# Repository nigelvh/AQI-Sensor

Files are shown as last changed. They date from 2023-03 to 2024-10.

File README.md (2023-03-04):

# AQI Sensor
Custom hardware for measuring the Air Quality Index along with environmental Temperature, Pressure, and Humidity. [Read more about the project here!](https://digitalnigel.com/wordpress/?p=3436)

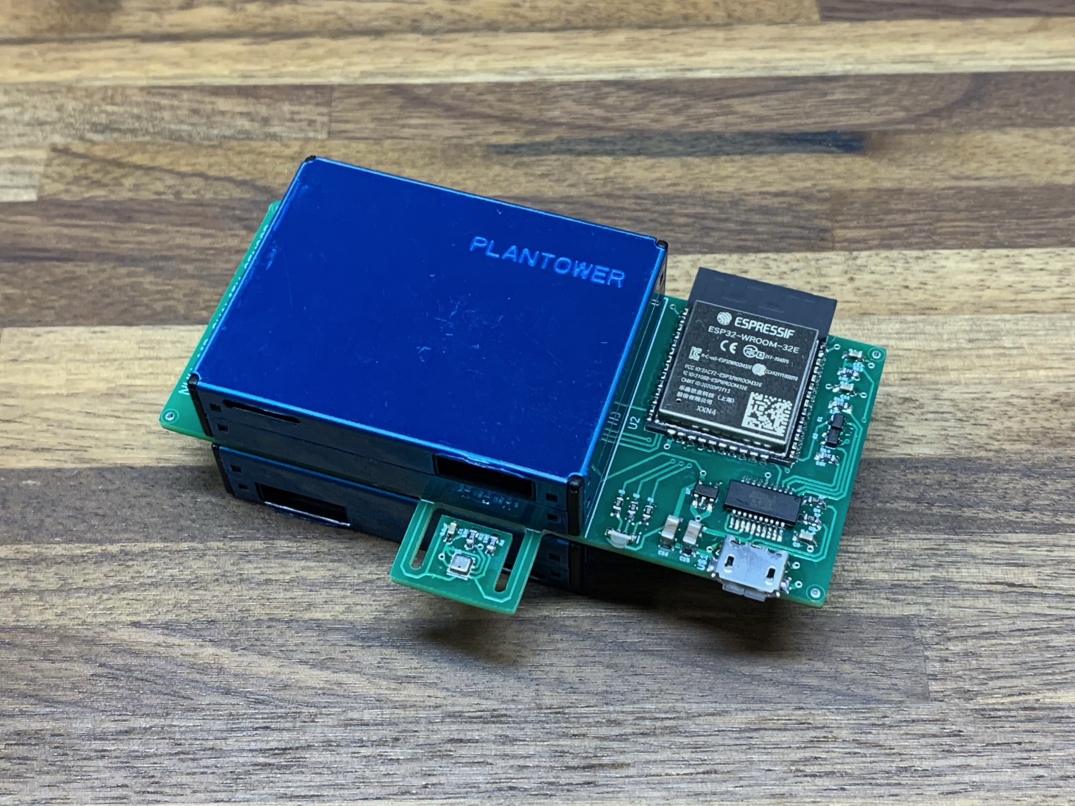
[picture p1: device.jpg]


## Hardware
The PCB designs for the device, as well as a STL for the 3D printed portion of the enclosure.

## Firmware
The firmware I run on my devices, written for MicroPython.

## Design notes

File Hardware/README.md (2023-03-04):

# AQI Sensor Hardware
This is a custom board for interfacing an ESP32 microcontroller with a pair of Plantower PMS7003 particulate sensors, and a Bosch Sensortec BME280 Temperature, Pressure, and Humidity sensor.

The hardware was designed, along with a 3D printed carrier, to mount inside a 3" PVC pipe cap for a simple and inexpensive outdoor enclosure. It should be noted that the design requires use of a 3" PVC pipe cap with a domed end. The flat face pipe caps will not let the board and carrier seat fully.

## Circuit Board
The schematic and board files have been created in Eagle, though I cannot guarantee how they will load without all of the associated libraries. The gerber files are also provided which can be sent directly to a PCB fab house. Additionally there are exported images of the schematic and board designs for review without using the Eagle CAD software.

A parts text file has been included to cover some of the more important, or more specific, parts used in the design. It is not all inclusive (I didn't include the passives for example), but it covers the main components.

## 3D Print
The board is designed to fit into a 3D printed carrier, and mount into a 3" PVC pipe cap to form the outdoor enclosure. I have printed these in PETG which was chosen for its properties when exposed to the elements. Your choices may differ.

The carrier was modelled in FreeCAD, but the STL has been provided as well to import directly into your slicer of choice.

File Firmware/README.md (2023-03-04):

# AQI Sensor Firmware
This firmware is specific to the device described in the hardware section. It is a chunk of code for use with [MicroPython](https://micropython.org/) on the ESP32. I have used the `esp32-20220618-v1.19.1.bin` MicroPython release in my deployments. I don't believe there's anything extraordinary in the code, but I can't guarantee other releases won't change something.

I make use of the [Microdot library](https://microdot.readthedocs.io/en/latest/index.html) to handle the web server portion of the application. For memory considerations, I pre-compiled the `microdot` and `microdot_asyncio` into their respective `.mpy` files.

All of the remaining libraries are shipped default with MicroPython or I have written and included myself.

## Tweaks
In `boot.py` you will need to fill in your own data for the `POST_URL` and `UPDATE_URL` fields.

The `POST_URL` field is simply the URL the device will send a POST request to once per minute, with JSON encoded data in the POST body. Parsing/storing/displaying that data is left as an exercise to the user.

The `UPDATE_URL` field is the URL *TO A FOLDER* where the device will expect to find a `version.json` file which will enumerate the files to be downloaded and their SHA1 sums for verification. I'm not going to document this further because it's probably garbage, but the `update.py` code shouldn't be terribly obtuse if you really want to use it.

## Disclaimer
I'm not a coder by trade. I don't make any guarantees about the quality of the code. In fact it's probably pretty bad. It works for me on my devices. If you have improvements, feel free to send them along.

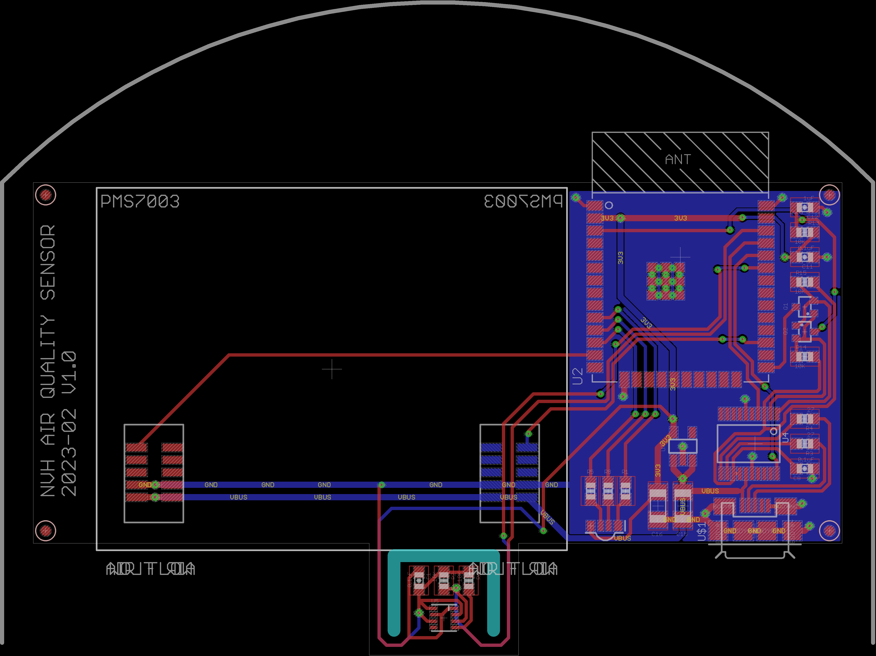
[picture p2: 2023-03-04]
Hardware/Circuit Board/Image_Board_V1.0_withPours.png

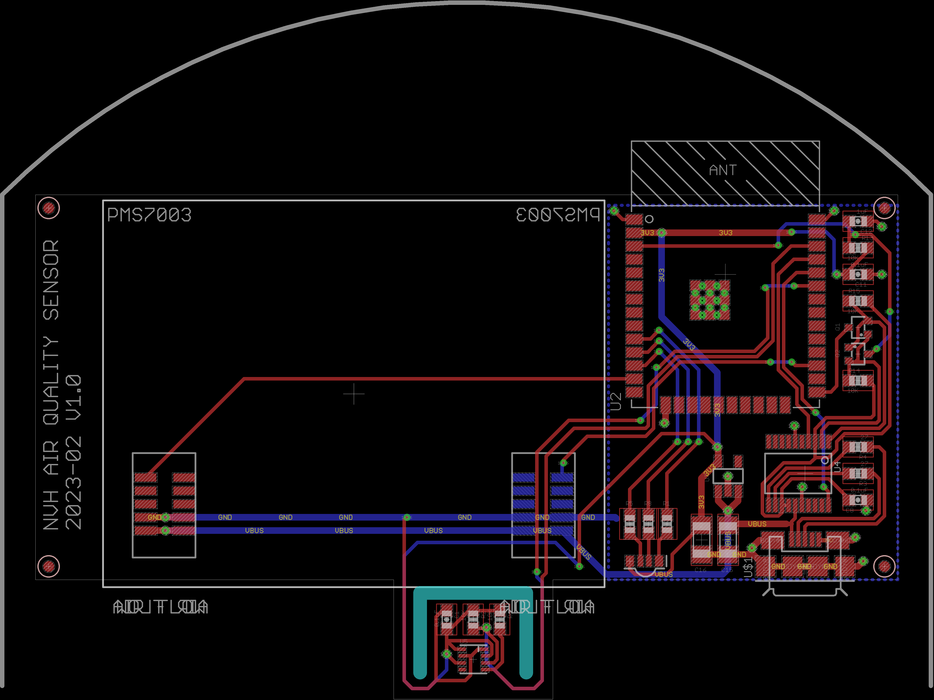
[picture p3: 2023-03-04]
Hardware/Circuit Board/Image_Board_V1.0_withoutPours.png

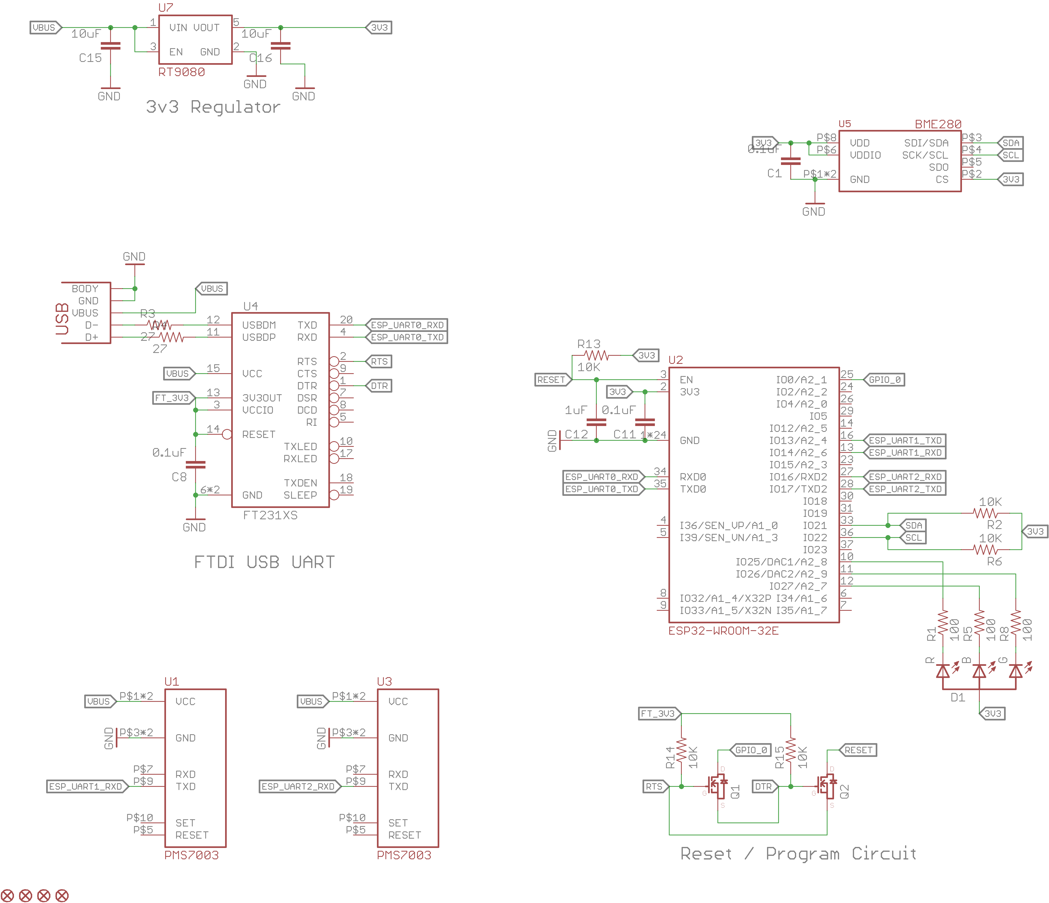
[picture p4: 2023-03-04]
Hardware/Circuit Board/Image_Schematic_V1.0.png

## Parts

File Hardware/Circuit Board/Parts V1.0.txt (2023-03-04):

PMS7003 Connector
	https://www.digikey.com/en/products/detail/amphenol-cs-fci/20021321-00010C1LF/4243101

BME280 Temperature/Pressure/Humidity
	https://www.digikey.com/en/products/detail/bosch-sensortec/BME280/6136306

ESP32
	https://www.digikey.com/en/products/detail/espressif-systems/ESP32-WROOM-32E-N4/11613125

FT231XS
	https://www.digikey.com/en/products/detail/ftdi-future-technology-devices-international-ltd/FT231XS-U/3749471
	
RGB LED
	https://www.digikey.com/en/products/detail/qt-brightek-qtb/QBLP615-RGB-3053/12318395

Reset Circuit Mosfets
	https://www.digikey.com/en/products/detail/diodes-incorporated/DMN61D9UWQ-13/7666847

3V3 Regulator
	https://www.digikey.com/en/products/detail/richtek-usa-inc/RT9080-33GJ5/6161634

USB Connector
	https://www.digikey.com/en/products/detail/amphenol-cs-fci/10118192-0001LF/2785387

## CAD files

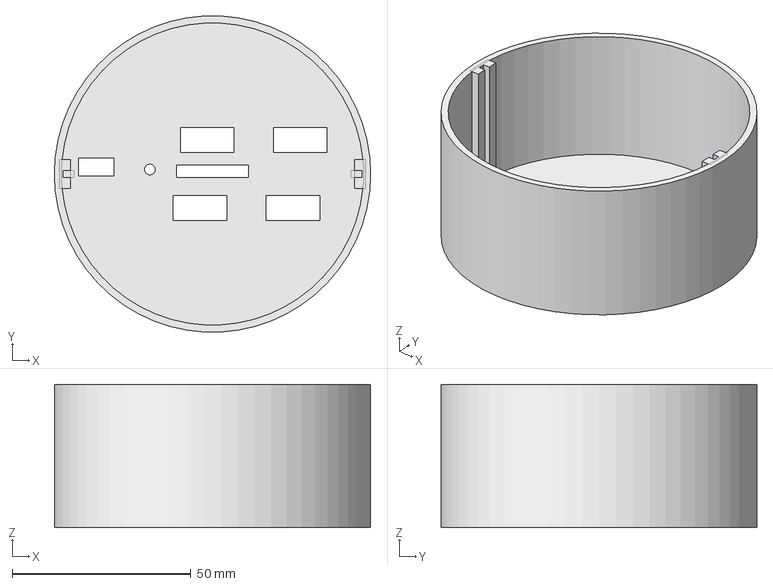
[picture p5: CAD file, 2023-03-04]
Hardware/3D Print/AQI Pipe Cap Carrier.FCStd
88.5 x 88.4 x 40.0 mm

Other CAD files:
Hardware/3D Print/AQI Pipe Cap Carrier.stl

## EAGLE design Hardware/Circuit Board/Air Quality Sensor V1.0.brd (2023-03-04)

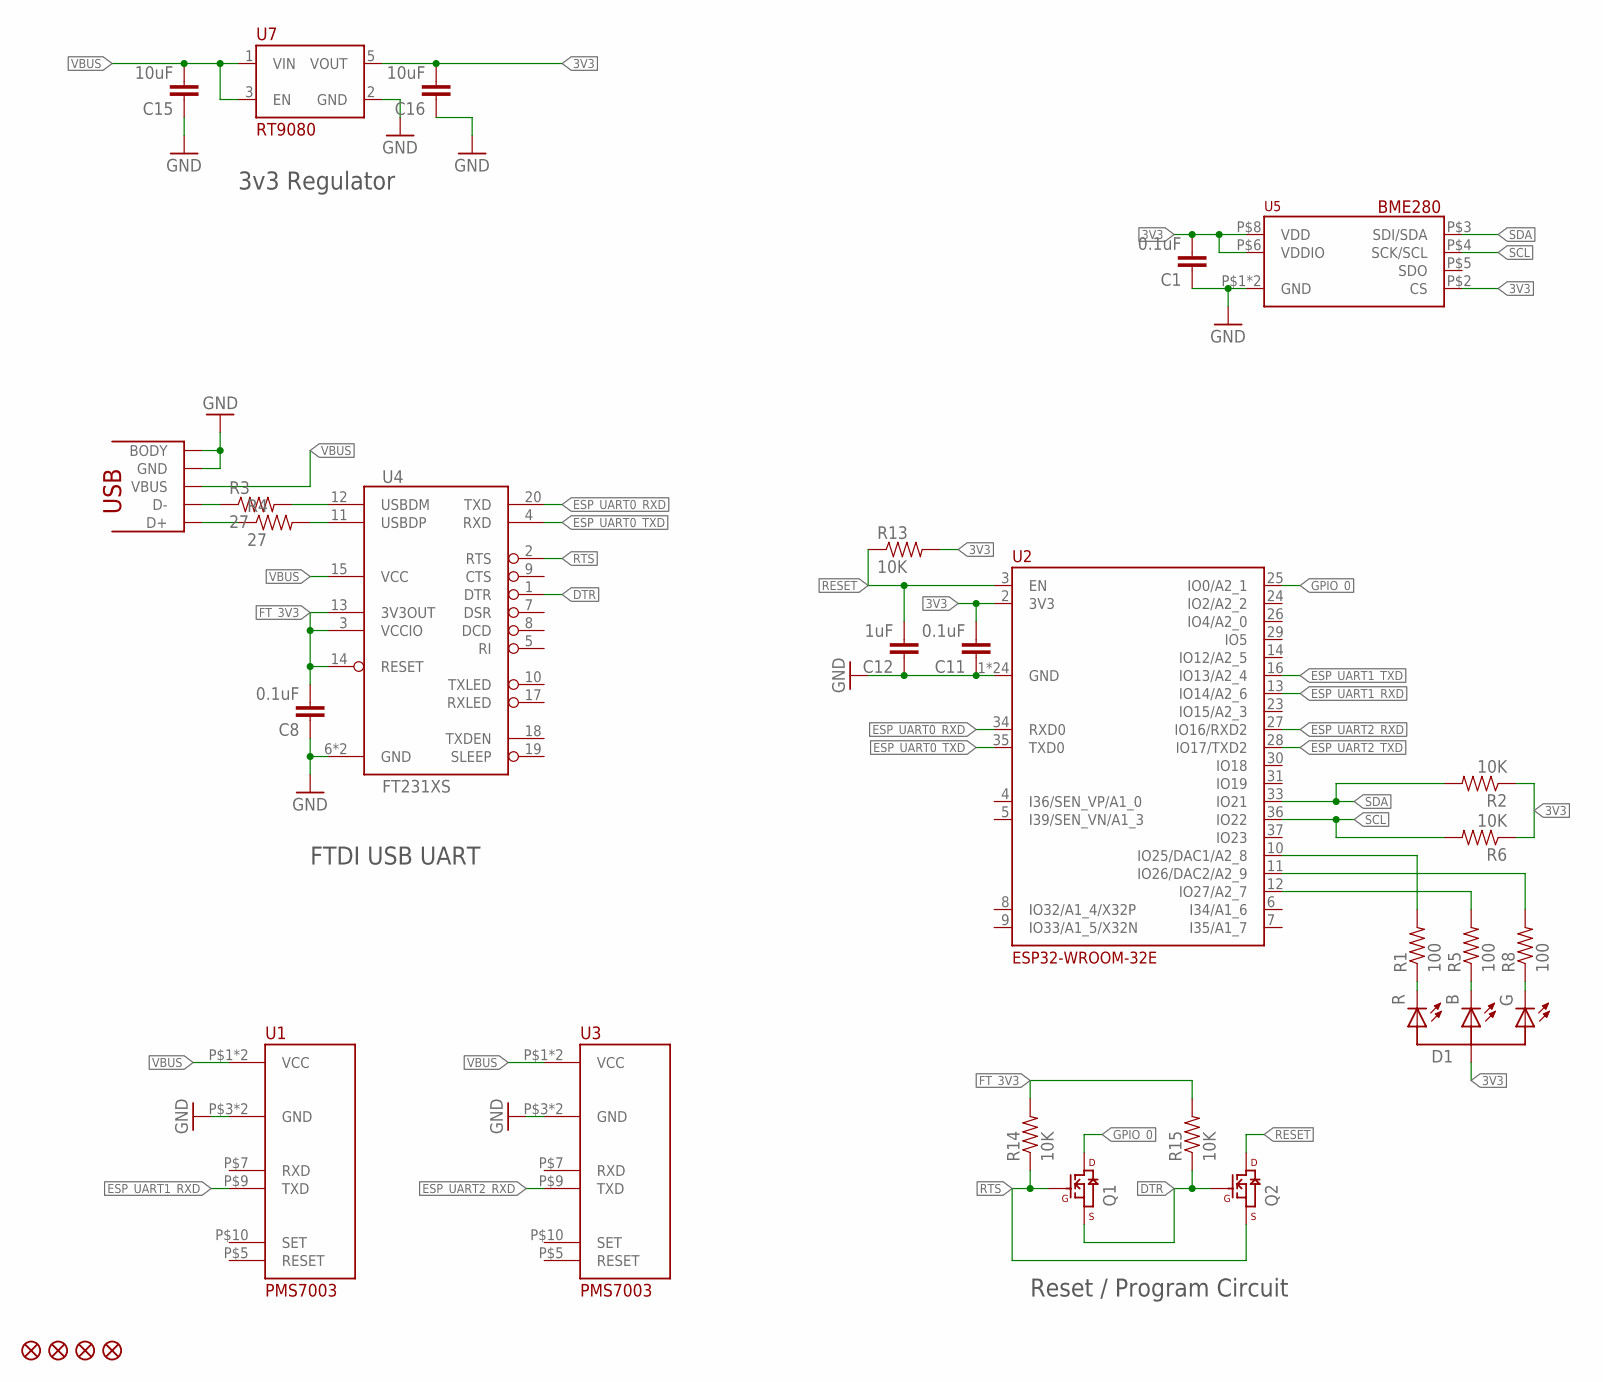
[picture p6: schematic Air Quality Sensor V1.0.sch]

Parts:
C1, C8, C11: 0.1uF; 0603-CAP
C12: 1uF; 0603-CAP
C15, C16: 10uF; 1206
D1: LED_TRICOLOR_COM-ANODE; LED_1206_SIDE_TRICOLOR
FID1, FID2, FID3, FID4: FIDUCIAL
Q1, Q2: MOSFET_N_CHANNELSI1308; SC-70-3
R1, R5, R8: 100; 0603-RES
R2, R6, R13, R14, R15: 10K; 0603-RES
R3, R4: 27; 0603-RES
U1, U3: PMS7003_SMD
U2: ESP32-WROOM-32E
U4: FT231XS; SSOP-20
U5: BME280; 8-VFLGA
U7: RT9080; SOT-23-5
U$1: USB-MICROB; USB-MICROB-10118192

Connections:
3V3: C1.2, C11.2, C16.2, D1.P$3 (A), R2.1, R6.1, R13.2, U2.2 (3V3), U5.P$2 (CS), U5.P$6 (VDDIO), U5.P$8 (VDD), U7.5 (VOUT)
DTR: Q1.P$2 (S), Q2.P$1 (G), R15.1, U4.1 (DTR)
ESP_UART0_RXD: U2.34 (RXD0), U4.20 (TXD)
ESP_UART0_TXD: U2.35 (TXD0), U4.4 (RXD)
ESP_UART1_RXD: U1.P$9 (TXD), U2.13 (IO14/A2_6)
ESP_UART1_TXD: U2.16 (IO13/A2_4)
ESP_UART2_RXD: U2.27 (IO16/RXD2), U3.P$9 (TXD)
ESP_UART2_TXD: U2.28 (IO17/TXD2)
FT_3V3: C8.2, R14.2, R15.2, U4.3 (VCCIO), U4.13 (3V3OUT), U4.14 (RESET)
GND: C1.1, C8.1, C11.1, C12.1, C15.1, C16.1, U1.P$3 (GND), U1.P$4 (GND), U2.1 (GND), U2.15 (GND), U2.38 (GND), U2.P$1 (GND), U2.P$2 (GND), U2.P$3 (GND), U2.P$4 (GND), U2.P$5 (GND), U2.P$6 (GND), U2.P$7 (GND), U2.P$8 (GND), U2.P$9 (GND), U2.P$10 (GND), U2.P$11 (GND), U2.P$12 (GND), U2.PAD@1 (GND), U2.PAD@2 (GND), U2.PAD@3 (GND), U2.PAD@4 (GND), U2.PAD@5 (GND), U2.PAD@6 (GND), U2.PAD@7 (GND), U2.PAD@8 (GND), U2.PAD@9 (GND), U3.P$3 (GND), U3.P$4 (GND), U4.6 (GND), U4.16 (GND), U5.P$1 (GND), U5.P$7 (GND), U7.2 (GND), U$1.5 (GND), U$1.BODY@1 (BODY), U$1.BODY@2 (BODY), U$1.BODY@3 (BODY), U$1.BODY@4 (BODY), U$1.BODY@5 (BODY), U$1.BODY@6 (BODY)
GPIO_0: Q1.P$3 (D), U2.25 (IO0/A2_1)
unnamed: R1.2, U2.10 (IO25/DAC1/A2_8)
unnamed: R8.2, U2.11 (IO26/DAC2/A2_9)
unnamed: R5.2, U2.12 (IO27/A2_7)
unnamed: D1.P$4 (C_RED), R1.1
unnamed: D1.P$2 (C_BLU), R5.1
unnamed: D1.P$1 (C_GRN), R8.1
unnamed: R3.1, U$1.2 (D-)
unnamed: R4.1, U$1.3 (D+)
unnamed: R4.2, U4.11 (USBDP)
unnamed: R3.2, U4.12 (USBDM)
RESET: C12.2, Q2.P$3 (D), R13.1, U2.3 (EN)
RTS: Q1.P$1 (G), Q2.P$2 (S), R14.1, U4.2 (RTS)
SCL: R6.2, U2.36 (IO22), U5.P$4 (SCK/SCL)
SDA: R2.2, U2.33 (IO21), U5.P$3 (SDI/SDA)
VBUS: C15.2, U1.P$1 (VCC), U1.P$2 (VCC), U3.P$1 (VCC), U3.P$2 (VCC), U4.15 (VCC), U7.1 (VIN), U7.3 (EN), U$1.1 (VBUS)

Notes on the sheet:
FTDI USB UART
3v3 Regulator
Reset / Program Circuit

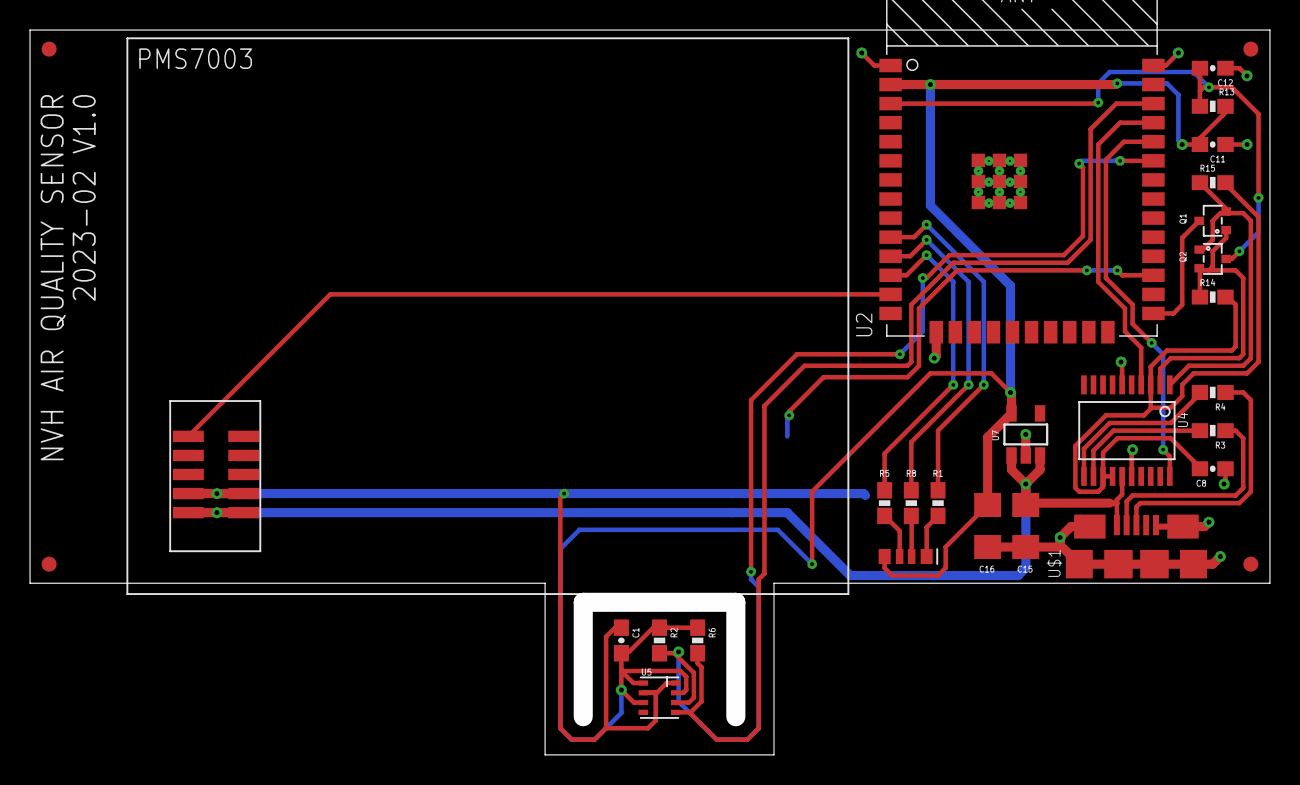
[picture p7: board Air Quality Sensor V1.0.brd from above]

Board: 2 copper layers, 82.5 x 48.3 mm, 30 parts (1 on the bottom side), 24 nets.

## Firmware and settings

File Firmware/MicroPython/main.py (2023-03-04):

import urequests
import ntptime
import uasyncio
import re
import sensor
import aqi
import web
from microdot_asyncio import Microdot, Response, send_file

# Set up our microdot app instance
app = Microdot()
Response.default_content_type = 'text/html'
web = web.WEB()

ntptime.host = prefs['SERVERS']['NTP_SERVER']

# Configure our BME instance
i2c = machine.I2C(1, scl=machine.Pin(22), sda=machine.Pin(21), freq=100000)
bme = sensor.BME280(i2c=i2c)
bme.start(standby=bme.BME_STANDBY_MS_62_5, filter=bme.BME_FILTER_4)

# Configure our PMS7003 instances
uart1 = machine.UART(1, baudrate=9600, bits=8, parity=None, stop=1, tx=13, rx=14, timeout=2000, timeout_char=2000)
uart2 = machine.UART(2, baudrate=9600, bits=8, parity=None, stop=1, tx=17, rx=16, timeout=2000, timeout_char=2000)
pms1 = sensor.PMS7003(uart=uart1)
pms2 = sensor.PMS7003(uart=uart2)

# Configure our AQI objects
aqi = aqi.AQI(pms1, pms2, bme)

# Define a flag for if a reboot has been requested
reboot_flag = False
reboot_time = 0

# Run 'mode' flag
run_mode = 0

# Validate that the string contains only printable ASCII chars
def wifi_match(strg):
	return bool(re.search(r'[ -~]$', strg))

@app.route('/', methods=['GET'])
@app.route('/index.html', methods=['GET'])
async def web_index(request):
	return web.generate_index(bme, pms1, pms2, aqi, wlan)

@app.route('/setup', methods=['GET', 'POST'])
@app.route('/setup.html', methods=['GET', 'POST'])
async def web_setup(request):
	alert_success_flag = False
	alert_reboot_flag = False
	alert_pass_flag = False
	global reboot_flag
	global reboot_time
	
	wlan_scan = wlan.scan()
	
	if request.method == 'POST':
		print(request.form)
		if request.form.get('submit') is not None:
			if request.form.get('passwd').lower() == setup_pw.lower():
				print('Setup page got submit request. Saving data...')
				print('SSID: %s\nPASS: %s\n' % (request.form.get('ssid'), request.form.get('pass')))
				if wifi_match(request.form.get('ssid')) and (wifi_match(request.form.get('pass')) or (len(request.form.get('pass')) == 0)):
					prefs['WIFI']['NETWORK'] = request.form.get('ssid')
					prefs['WIFI']['PASSWORD'] = request.form.get('pass')
					settings_json = ujson.dumps(prefs)
					try:
						prefs_fp = open(prefs_file_path, 'w')
						prefs_fp.write(settings_json)
						prefs_fp.close()
						alert_success_flag = True
					except Exception as e:
						print("EXCEPTION: %s" % e)
				else:
					print('Failed to validate wifi SSID and PASS.')
			else:
				print('Incorrect setup password')
				alert_pass_flag = True
		if request.form.get('reboot') is not None:
			if request.form.get('passwd').lower() == setup_pw.lower():
				print('Setup page got reboot request. Rebooting...')
				reboot_flag = True
				reboot_time = utime.ticks_ms()
				alert_reboot_flag = True
			else:
				print('Incorrect setup password')
				alert_pass_flag = True
		if request.form.get('defaults') is not None:
			if request.form.get('passwd').lower() == setup_pw.lower():
				print('Setup page got defaults reset request. Clearing prefs and rebooting...')
				try:
					os.remove(prefs_file_path)
				except Exception as e:
					print("EXCEPTION: %s" % e)
				reboot_flag = True
				reboot_time = utime.ticks_ms()
				alert_reboot_flag = True
			else:
				print('Incorrect setup password')
				alert_pass_flag = True
				
	return web.generate_setup(scan_data=wlan_scan, alert_success=alert_success_flag, alert_reboot=alert_reboot_flag, alert_pass=alert_pass_flag)

@app.route('/style.css')
async def web_bootstrap_css(request):
	return send_file('style.css')

# Background task on 1 minute timer
async def loop_1m():
	upload_fail_count = 0
	
	while(True):
		await uasyncio.sleep(60)

		# Read sensors
		bme.read()
		pms1.fresh_read()
		pms2.fresh_read()

		# At 15 minutes past the hour, update time via NTP
		if utime.localtime()[4] == 15:
			print("Sync time: {:s}".format(prefs['SERVERS']['NTP_SERVER']))
			try:
				ntptime.settime()
				print("Updated time：%s" %str(utime.localtime()))
			except:
				print("ERR: NTP")

		# Output some data
		pre_gc_free = gc.mem_free()
		gc.collect()
		post_gc_free = gc.mem_free()

		print("MEM - PRE: %d, POST: %d" % (pre_gc_free, post_gc_free))
		print("AQI - PM2.5: %d, PM10.0: %d" % (aqi.get_aqi_pm2_5() , aqi.get_aqi_pm10_0()))
		print("PMS1 AGE: %d, PMS2 AGE: %d" % ((utime.ticks_ms() - pms1.LAST_UPDATE), (utime.ticks_ms() - pms2.LAST_UPDATE)))
		print("ENV - TEMP: %f, HUM: %f, PRESS: %f" % (bme.temperature, bme.humidity, bme.pressure))

		if wlan.isconnected():
			post_headers = {'content-type': 'application/json'}
			post_data = {'NODE': {
							'MAC': hex(wlan.config('mac')[0])[2:] + ":" + hex(wlan.config('mac')[1])[2:] + ":" + hex(wlan.config('mac')[2])[2:] + ":" + hex(wlan.config('mac')[3])[2:] + ":" + hex(wlan.config('mac')[4])[2:] + ":" + hex(wlan.config('mac')[5])[2:],
							'SW_VERS_NUM': sw_version,
							'UNIT_ID': unit_id,
							'TIMESTAMP': utime.localtime(),
							'RESET_CAUSE': machine.reset_cause(),
							'RESET_TIME': utime.ticks_ms(),
							'FAIL_COUNT': upload_fail_count
							},
						'CONNECTION': {
							'NETWORK': wlan.config('essid'),
							'RSSI': wlan.status('rssi'),
							'IP': wlan.ifconfig()[0]
							},
						'DATA': {
							'ENVIRONMENT': {
								'TEMPERATURE': bme.temperature,
								'PRESSURE': bme.pressure,
								'HUMIDITY': bme.humidity
								},
							'AQI': {
								'AQI_PM2_5': int(aqi.get_aqi_pm2_5()),
								'AQI_PM2_5_CONFIDENCE': int(aqi.calc_confidence_pm2_5()),
								'AQI_PM10_0': int(aqi.get_aqi_pm10_0()),
								'AQI_PM10_0_CONFIDENCE': int(aqi.calc_confidence_pm10_0())
								},
							'PARTICULATE': {
								'SENSOR_A': {
									'1HR_AVG_PM2_5': pms1.get_average_2_5(),
									'1HR_AVG_PM10_0': pms1.get_average_10_0(),
									'CF1_PM1_0': pms1.CF1_PM1_0,
									'CF1_PM2_5': pms1.CF1_PM2_5,
									'CF1_PM10_0': pms1.CF1_PM10_0,
									'ATM_PM1_0': pms1.ATM_PM1_0,
									'ATM_PM2_5': pms1.ATM_PM2_5,
									'ATM_PM10_0': pms1.ATM_PM10_0,
									'RAW_0_3': pms1.RAW_0_3,
									'RAW_0_5': pms1.RAW_0_5,
									'RAW_1_0': pms1.RAW_1_0,
									'RAW_2_5': pms1.RAW_2_5,
									'RAW_5_0': pms1.RAW_5_0,
									'RAW_10_0': pms1.RAW_10_0,
									'VERSION': pms1.VERSION,
									'ERROR': pms1.ERROR,
									'LAST_UPDATE': (utime.ticks_ms() - pms1.LAST_UPDATE)
									},
								'SENSOR_B': {
									'1HR_AVG_PM2_5': pms2.get_average_2_5(),
									'1HR_AVG_PM10_0': pms2.get_average_10_0(),
									'CF1_PM1_0': pms2.CF1_PM1_0,
									'CF1_PM2_5': pms2.CF1_PM2_5,
									'CF1_PM10_0': pms2.CF1_PM10_0,
									'ATM_PM1_0': pms2.ATM_PM1_0,
									'ATM_PM2_5': pms2.ATM_PM2_5,
									'ATM_PM10_0': pms2.ATM_PM10_0,
									'RAW_0_3': pms2.RAW_0_3,
									'RAW_0_5': pms2.RAW_0_5,
									'RAW_1_0': pms2.RAW_1_0,
									'RAW_2_5': pms2.RAW_2_5,
									'RAW_5_0': pms2.RAW_5_0,
									'RAW_10_0': pms2.RAW_10_0,
									'VERSION': pms2.VERSION,
									'ERROR': pms2.ERROR,
									'LAST_UPDATE': (utime.ticks_ms() - pms2.LAST_UPDATE)
									}
								}
							}
						}

			gc.collect()

			try:
				result = urequests.post(prefs['SERVERS']['POST_URL'], headers = post_headers, data = ujson.dumps(post_data))
				result.close()
			except Exception as e:
				print("ERR: Upload sensor data")
				print(e)
				upload_fail_count = upload_fail_count + 1
			else:
				print("Data uploaded.")
				upload_fail_count = 0
		else:
			print("ERR: No WiFi during upload!")
		
		if upload_fail_count > 15:
			print("ERR: Upload fail count")
			machine.reset()

# Background task on 1 second timer
async def loop_1s():
	while(True):
		# Check for reboot flag
		if reboot_flag:
			print("Reboot flag. Diff: %d" % utime.ticks_diff(utime.ticks_ms(), reboot_time))
			if utime.ticks_diff(utime.ticks_ms(), reboot_time) > 5000:
				machine.reset()
		
		# Run some garbage collection
		if gc.mem_free() < 32768:
			print("GC TASK: Free Mem: %d" % gc.mem_free(), end=" ")
			gc.collect()
			print("GC TASK: Collect... Free Mem: %d" % gc.mem_free())
				
		await uasyncio.sleep_ms(1000)

async def main():
	global run_mode
	while(True):
		# If we don't have a preferences file, enter setup mode
		if prefs_set == False:
			rgbled.blink = True
			rgbled.color = rgbled.ORANGE
		
			wlan.active(True)
			wlan_ap.active(True)
			
			print('No configuration. Enter setup. Start AP.')
			print('Network:', wlan_ap.ifconfig())
			print('Reboot in 10 min.')
			
			await uasyncio.sleep(600)
			print('10 min expired. Reboot...')
			machine.reset()
			
		else:
			# Run mode 0 - Fresh boot, try to connect to a hotspot for config
			if run_mode == 0:
				rgbled.blink = True
				rgbled.color = rgbled.TEAL
			
				if not wlan.isconnected():
					print('Trying setup net...')
					wlan_ap.active(False)
					wlan.active(True)
					wlan.connect('NVH_AQI', ("NVHAQI" + setup_pw))
					wifi_connect_wait = 0
					while not wlan.isconnected():
						await uasyncio.sleep(1)
						wifi_connect_wait = wifi_connect_wait + 1
						if wifi_connect_wait > 10:
							print("No setup network. Normal boot...")
							wlan.disconnect()
							run_mode = 1
							break
					
					if wlan.isconnected():
						# We were able to connect to the config network
						print('Setup network! Reboot in 10 min.')
						print('Network:', wlan.ifconfig())
						rgbled.blink = False
						await uasyncio.sleep(600)
						print('10 min expired. Reboot...')
						machine.reset()
			
			# Run mode 1 - Fresh boot, after we've tried finding the config hotspot, connect to normal wifi config
			elif run_mode == 1:
				rgbled.blink = True
				rgbled.color = rgbled.BLUE
			
				print('Connect to wifi...')
				wlan_ap.active(False)
				wlan.active(True)
				wlan.disconnect()
				wlan.connect(prefs['WIFI']['NETWORK'], prefs['WIFI']['PASSWORD'])
				wifi_connect_wait = 0
				while not wlan.isconnected():
					await uasyncio.sleep(1)
					wifi_connect_wait = wifi_connect_wait + 1
					if wifi_connect_wait > 30:
						print("Not connected.")
						wlan.disconnect()
						run_mode = 2
						break
				
				if wlan.isconnected():
					# We were able to connect to the normal wifi config
					rgbled.blink = False
					print('Connect success!')
					print('Network:', wlan.ifconfig())
					run_mode = 3
			
			# Run mode 2 - Failed to connect to normal wifi config
			elif run_mode == 2:
				rgbled.blink = True
				rgbled.color = rgbled.RED

				wlan.active(True)
				wlan_ap.active(True)
			
				print('No WiFi. Enter setup. Start AP.')
				print('Network:', wlan_ap.ifconfig())
				print('Reboot in 10 min.')
			
				await uasyncio.sleep(600)
				print('10 min expired. Reboot...')
				machine.reset()
			
			# Run mode 3 - Connected to normal wifi
			elif run_mode == 3:
				rgbled.blink = False
				rgbled.color = rgbled.GREEN
				
				print("Sync time: {:s}".format(prefs['SERVERS']['NTP_SERVER']))
				try:
					ntptime.settime()
					print("Updated time：%s" %str(utime.localtime()))
				except:
					print("ERR: NTP")

				await uasyncio.sleep(2)
				rgbled.blink = False
				rgbled.color = rgbled.BLACK

				wifi_fail_count = 0
				while(True):
					# Keep track of if we've lost wifi
					if wlan.isconnected():
						wifi_fail_count = 0
					else:
						wifi_fail_count = wifi_fail_count + 1
					
					# If we've lost wifi for more than 15 minutes, reboot.
					if wifi_fail_count > 15:
						machine.reset()
					
					await uasyncio.sleep(60)

		# Do stuff
		await uasyncio.sleep_ms(2000)
			
# MAIN
try:
	# Background tasks
	uasyncio.create_task(loop_1s())
	uasyncio.create_task(loop_1m())
	uasyncio.create_task(rgbled.run())
	uasyncio.create_task(main())
	app.run(host='0.0.0.0', port=80)

except Exception as e:
	# Potentially do something with the exception
	print("EXCEPTION:")
	print(e)
	print("Reset...")
	machine.reset()

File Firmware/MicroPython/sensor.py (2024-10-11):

import math
import utime
import struct

class PMS7003:
	# Start Bytes
	PMS_START_BYTE_1 = const(0x42)
	PMS_START_BYTE_2 = const(0x4D)

	# Data Field Positions
	PMS_FIELD_POS_FRAME_LENGTH = const(0)
	PMS_FIELD_POS_CF1_PM1_0 = const(1)
	PMS_FIELD_POS_CF1_PM2_5 = const(2)
	PMS_FIELD_POS_CF1_PM10_0 = const(3)
	PMS_FIELD_POS_ATM_PM1_0 = const(4)
	PMS_FIELD_POS_ATM_PM2_5 = const(5)
	PMS_FIELD_POS_ATM_PM10_0 = const(6)
	PMS_FIELD_POS_RAW_0_3 = const(7)
	PMS_FIELD_POS_RAW_0_5 = const(8)
	PMS_FIELD_POS_RAW_1_0 = const(9)
	PMS_FIELD_POS_RAW_2_5 = const(10)
	PMS_FIELD_POS_RAW_5_0 = const(11)
	PMS_FIELD_POS_RAW_10_0 = const(12)
	PMS_FIELD_POS_VERSION = const(13)
	PMS_FIELD_POS_ERROR = const(14)
	PMS_FIELD_POS_CHECKSUM = const(15)

	def __init__(self, uart=None, avg_samples=60):
		# Validate inputs
		if uart is None:
			raise ValueError("Invalid uart object.")
		
		self._uart = uart
		self._avg_samples_len = avg_samples
		
		self.LAST_UPDATE = 0
		self.CF1_PM1_0 = 0
		self.CF1_PM2_5 = 0
		self.CF1_PM10_0 = 0
		self.ATM_PM1_0 = 0
		self.ATM_PM2_5 = 0
		self.ATM_PM10_0 = 0
		self.RAW_0_3 = 0
		self.RAW_0_5 = 0
		self.RAW_1_0 = 0
		self.RAW_2_5 = 0
		self.RAW_5_0 = 0
		self.RAW_10_0 = 0
		self.VERSION = 0
		self.ERROR = 0

		self._avg_samples_2_5 = []
		self._avg_samples_10_0 = []
		for x in range(self._avg_samples_len):
			self._avg_samples_2_5.append(0)
			self._avg_samples_10_0.append(0)
		
		self.fresh_read()
		for x in range(self._avg_samples_len):
			self._avg_samples_2_5[x] = self.ATM_PM2_5
			self._avg_samples_10_0[x] = self.ATM_PM10_0

	def fresh_read(self):
		self._flush_input()
		return self.read()
	
	def read(self):
		# Loop through at most 32 bytes looking for the start byte
		loops = 0
		while True:
			temp_start_1 = self._read_byte()
			if temp_start_1 is False:
				return False
			if temp_start_1 is None:
				return False
			if ord(temp_start_1) == self.PMS_START_BYTE_1:
				break
			loops = loops + 1
			if loops > 32:
				return False

		# After we've found the start byte, look for the second start byte
		temp_start_2 = self._read_byte()
		if temp_start_2 is False:
			return False
		if temp_start_2 is None:
			return False
		if ord(temp_start_2) != self.PMS_START_BYTE_2:
			return False
	
		# We've gotten both start bytes, grab the next 30 bytes of data
		frame_data = self._read_num_bytes(30)
		if frame_data is False:
			return False
		if frame_data is None:
			return False
		
		# Unpack the binary data
		data = struct.unpack('!HHHHHHHHHHHHHBBH', frame_data)
		
		# Validate the checksum
		checksum = self.PMS_START_BYTE_1 + self.PMS_START_BYTE_2 + sum(frame_data[:28])
		if checksum != data[self.PMS_FIELD_POS_CHECKSUM]:
			print("Checksum invalid.")
			return False
		
		# Save the data and update the LAST_UPDATE var
		self.CF1_PM1_0 = data[self.PMS_FIELD_POS_CF1_PM1_0]
		self.CF1_PM2_5 = data[self.PMS_FIELD_POS_CF1_PM2_5]
		self.CF1_PM10_0 = data[self.PMS_FIELD_POS_CF1_PM10_0]
		self.ATM_PM1_0 = data[self.PMS_FIELD_POS_ATM_PM1_0]
		self.ATM_PM2_5 = data[self.PMS_FIELD_POS_ATM_PM2_5]
		self.ATM_PM10_0 = data[self.PMS_FIELD_POS_ATM_PM10_0]		
		self.RAW_0_3 = data[self.PMS_FIELD_POS_RAW_0_3]
		self.RAW_0_5 = data[self.PMS_FIELD_POS_RAW_0_5]
		self.RAW_1_0 = data[self.PMS_FIELD_POS_RAW_1_0]
		self.RAW_2_5 = data[self.PMS_FIELD_POS_RAW_2_5]
		self.RAW_5_0 = data[self.PMS_FIELD_POS_RAW_5_0]
		self.RAW_10_0 = data[self.PMS_FIELD_POS_RAW_10_0]
		self.VERSION = data[self.PMS_FIELD_POS_VERSION]
		self.ERROR = data[self.PMS_FIELD_POS_ERROR]
		self.LAST_UPDATE = utime.ticks_ms()

		self._avg_samples_2_5.insert(0, self.ATM_PM2_5)
		self._avg_samples_2_5.pop()
		self._avg_samples_10_0.insert(0, self.ATM_PM10_0)
		self._avg_samples_10_0.pop()

		return True

	def get_average_2_5(self):
		return sum(self._avg_samples_2_5) / len(self._avg_samples_2_5)

	def get_average_10_0(self):
		return sum(self._avg_samples_10_0) / len(self._avg_samples_10_0)
	
	def _debug_avg_2_5(self):
		for x in range(len(self._avg_samples_2_5)):
			print(self._avg_samples_2_5[x])

	def _debug_avg_10_0(self):
		for x in range(len(self._avg_samples_10_0)):
			print(self._avg_samples_10_0[x])

	def _flush_input(self):
		loops = 0
		while(self._uart.any() > 0):
			self._uart.read(self._uart.any())
			loops = loops + 1
			if loops > 255:
				break
		return True
	
	def _read_byte(self):
		working = self._uart.read(1)
		if (working is None) or (len(working) < 1):
			return False
		return working
	
	def _read_num_bytes(self, num_bytes):
		working = self._uart.read(num_bytes)
		if (working is None) or (len(working) < num_bytes):
			return False
		return working

class BME280:
	# Oversampling Options
	BME_OVERSAMPLE_SKIP = const(0)
	BME_OVERSAMPLE_X1 = const(1)
	BME_OVERSAMPLE_X2 = const(2)
	BME_OVERSAMPLE_X4 = const(3)
	BME_OVERSAMPLE_X8 = const(4)
	BME_OVERSAMPLE_X16 = const(5)

	# Filter Coefficient Options
	BME_FILTER_OFF = const(0)
	BME_FILTER_2 = const(1)
	BME_FILTER_4 = const(2)
	BME_FILTER_8 = const(3)
	BME_FILTER_16 = const(4)

	# Normal Mode Standby Time Options
	BME_STANDBY_MS_0_5 = const(0)
	BME_STANDBY_MS_62_5 = const(1)
	BME_STANDBY_MS_125 = const(2)
	BME_STANDBY_MS_250 = const(3)
	BME_STANDBY_MS_500 = const(4)
	BME_STANDBY_MS_1000 = const(5)
	BME_STANDBY_MS_10 = const(6)
	BME_STANDBY_MS_20 = const(7)

	# Sampling Mode
	BME_MODE_SLEEP = const(0)
	BME_MODE_FORCED = const(1)
	BME_MODE_NORMAL = const(3)

	# Chip Data
	BME_REGISTER_CHIPID = const(0xD0)
	BME_REGISTER_VERSION = const(0xD1)

	# Calibration Data
	BME_REGISTER_COMP_T1 = const(0x88)
	BME_REGISTER_COMP_T2 = const(0x8A)
	BME_REGISTER_COMP_T3 = const(0x8C)
	BME_REGISTER_COMP_P1 = const(0x8E)
	BME_REGISTER_COMP_P2 = const(0x90)
	BME_REGISTER_COMP_P3 = const(0x92)
	BME_REGISTER_COMP_P4 = const(0x94)
	BME_REGISTER_COMP_P5 = const(0x96)
	BME_REGISTER_COMP_P6 = const(0x98)
	BME_REGISTER_COMP_P7 = const(0x9A)
	BME_REGISTER_COMP_P8 = const(0x9C)
	BME_REGISTER_COMP_P9 = const(0x9E)
	BME_REGISTER_COMP_H1 = const(0xA1)
	BME_REGISTER_COMP_H2 = const(0xE1)
	BME_REGISTER_COMP_H3 = const(0xE3)
	BME_REGISTER_COMP_H4 = const(0xE4)
	BME_REGISTER_COMP_H5 = const(0xE5)
	BME_REGISTER_COMP_H6 = const(0xE6)
	BME_REGISTER_COMP_H7 = const(0xE7)

	# Control Registers
	BME_REGISTER_RESET = const(0xE0)
	BME_REGISTER_RESET_VALUE = const(0xB6)
	BME_REGISTER_CONTROL_HUM = const(0xF2)
	BME_REGISTER_STATUS = const(0xF3)
	BME_REGISTER_CONTROL = const(0xF4)
	BME_REGISTER_CONFIG = const(0xF5)

	# Sample Registers
	BME_REGISTER_SAMPLE_PRESSURE = const(0xF7)
	BME_REGISTER_SAMPLE_TEMPERATURE = const(0xFA)
	BME_REGISTER_SAMPLE_HUMIDITY = const(0xFD)

	# Default I2C Address
	BME_ADDRESS = const(0x76)
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

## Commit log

2023-03-04 Add Hardware directory, along with the board files, and 3d model for the carrier.
    [AQI Pipe Cap Carrier.FCStd, AQI Pipe Cap Carrier.stl, Air Quality Sensor V1.0.brd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]
2024-10-11 Better error handling in cases where we don't have the particulate sensors installed.
    [sensor.py]

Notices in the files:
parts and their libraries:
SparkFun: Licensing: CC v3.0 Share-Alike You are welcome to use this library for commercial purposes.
